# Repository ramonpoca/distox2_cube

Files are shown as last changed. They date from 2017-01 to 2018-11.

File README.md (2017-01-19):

# Readme #

OpenSCAD models for distox2 calibration device by Mykyta Kozlov. Version 0.0.5.

# Brief #

Calibration device consists of 2 things: calibration solid with direction holes, distox2 mounting handle.

Currently there are 2 OpenSCAD models of solid: cube and truncated cuboctahedron.

Cube corresponds to calibration directions used in [distox2 calibration manual](http://paperless.bheeb.ch/download/DistoX2_CalibrationManual.pdf).

Truncated cuboctahedron provides additional 12 calibration directions, saving 'original' cube ones.

Also provided 2 models of handle: 

1. To be printed from plastic and ready to use
2. More robust handle to use aluminiun pipe or shaft as main rotating unit. Aluminium part needs to be glued into plastic printed part. Optionally handle v.2 extension can be also used.

# HOWTO produce STL files for 3D printing #

1. Open .scad files in latest [OpenSCAD](http://www.openscad.org/).
2. Render (press F6).
3. Export to STL via menu item: File -> Export -> Export as STL.

# Pictures #

* Cube

Cube

* Truncated cuboctahedron

Truncated cuboctahedron

* Handle

Handle

* Handle v. 2

Handle v2

* Handle v. 2 extension

Handle v2 extension
Handle v2 extension bottom

# Sample mount #

Here goes an implementation example of mounting device to fix cube on tripod. Design by Vytis Vilkas.

* Bottom view

Bottom view

* Side view

Side view

* Alltogether

Alltogether

As it can be seen from photos above - cube is mounted to square O-shape rod by two non-magnetic screws.

There are space of 5 mm width left between rod surface and cube face - to allow free handle rotation, while doing calibration measurements along the rod.

Rod also has a bottom hole - for access while doing vertical calibration measurement with that hole.

For mounting truncated cuboctahedron rod needs to have additional 45 degree hole to acces calibration hole in cube edge.

Also solid aluminium handle is shown. If doing handle from plastic, especially handle v2 - you need to glue 8 mm nonmagnetic 
rotation axis into 8 mm handle hole. For truncated cuboctahedron axis length needs to be 2 time more than in original design,
again - to access hole in cube edge. Additionally handle v2 extension can be used to access keyhole trough the rod.

Second hole in handle's U-shape used for mounting leica disto x310 to handle by 1/4" nonmagnetic screw (same as used to mounting photo camera to tripod).

In the left side there are aluminium nut and aluminium screw, both having 1/4" screw are mounted through the rod to each other.
They are in 'transportation mode'. When doing calibration - screw is used to attach leica to rotating handle, nut is used to mount rod to standart tripods plate.

# Notes #

Handle design is compatible with leica disto X310 (E7400x US version of the X310) only.

To model your own calibration shape solid you can use Wolfram Mathematica notebook DistoX_Cube_shape_variants.nb,
which provides sample usage of polyhedron data and the way how to convert it into OpenSCAD format. You need Wolfram Mathematica to open such file.

After printing hole and shaft surfaces need to be finished to desired level of friction. Usualy enough to freely rotate, but not falling down being inserted into hole.

Handle v2 and Truncated cuboctahedron also has squared keys to optionally restrict rotation step around calibration axis by multiply of 45 degree.

# Sample usage video #

Calibrating distox2 with cube in Lithuanian forest (https://www.youtube.com/watch?v=A7fQdz4pPtE)

# Discussion #

* English

1. [Reddit's /r/caving](https://www.reddit.com/r/caving/comments/56mu1l/distox2_calibration_device/).
2. [Cavers of Facebook](https://www.facebook.com/groups/2205123638/permalink/10153870390228639/).

* Russian

1. [Speleoukraine forum](http://www.speleoukraine.org/forum/viewtopic.php?f=19&t=267&sid=d517e04313eabdb7c628c214259eedf8#p4050).
2. [Soumgan forum](http://www.soumgan.com/phpBB2/viewtopic.php?f=24&t=798).

# Contact #

If any questions contact nikita.kozlov@gmail.com

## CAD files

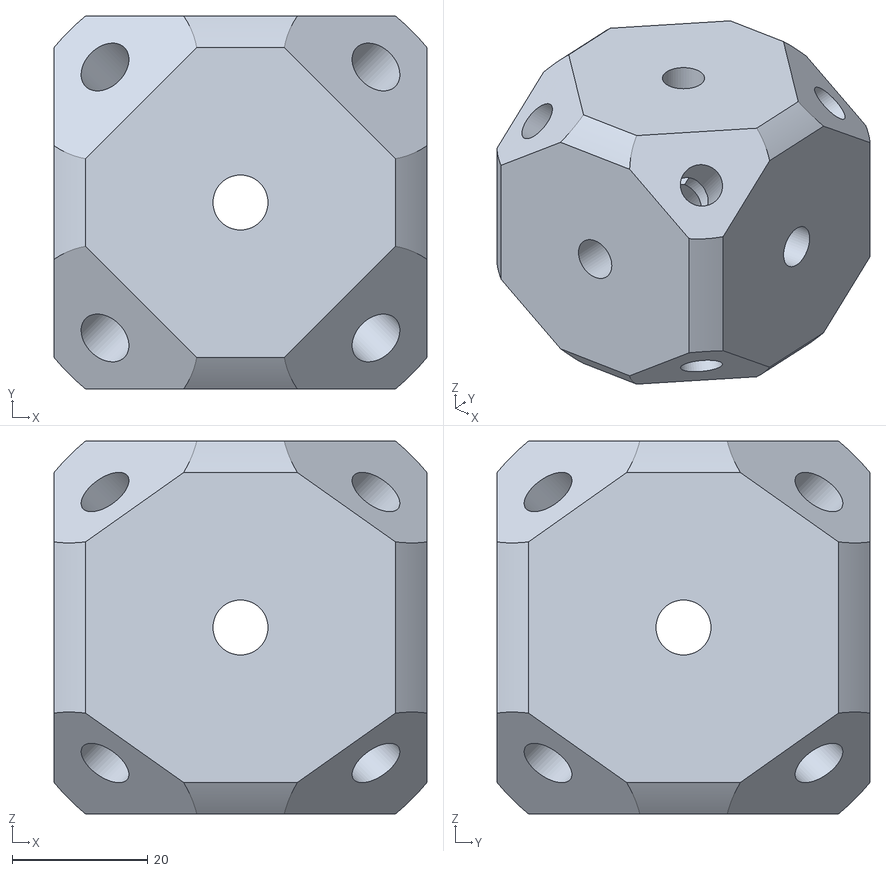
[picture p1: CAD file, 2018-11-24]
distox2_calibration_cube.stl
55.0 x 55.0 x 55.0

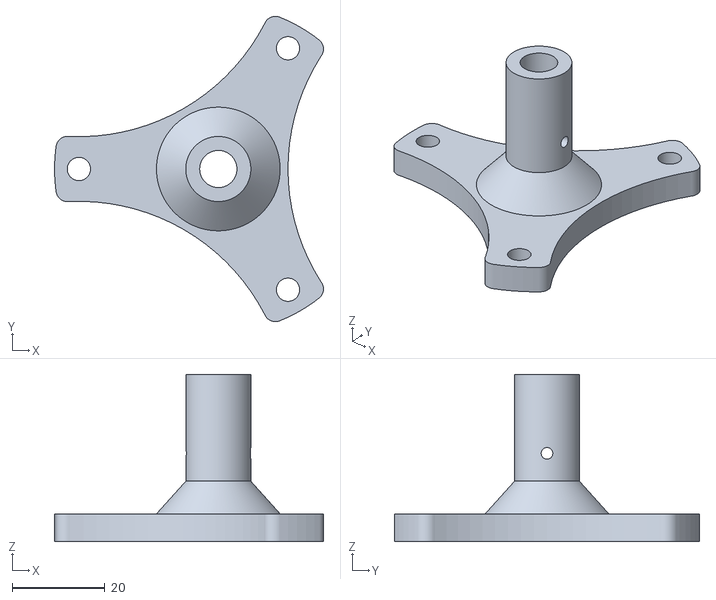
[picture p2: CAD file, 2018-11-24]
distox2_calibration_handle_v4_top.stl
57.9 x 65.7 x 36.0

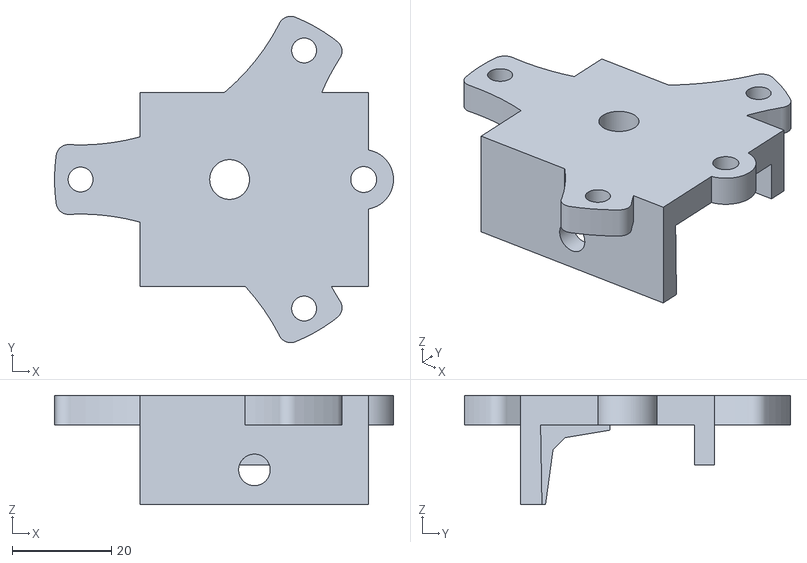
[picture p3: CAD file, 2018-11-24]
distox2_calibration_handle_v4_bot.stl
68.2 x 65.7 x 22.0

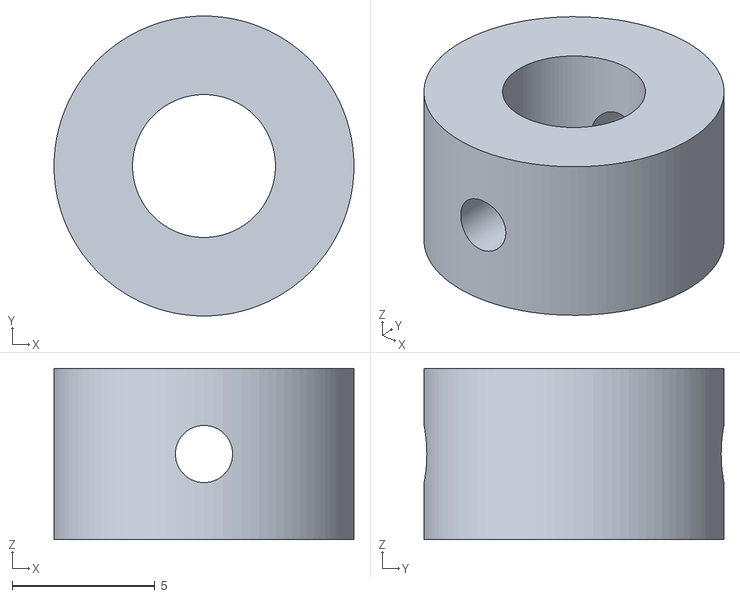
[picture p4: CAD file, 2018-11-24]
distox2_calibration_handle_v4_bolt_head.stl
10.5 x 10.5 x 6.00

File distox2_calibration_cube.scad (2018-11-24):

/// DistoX2 calibration cube by Mykyta Kozlov

hf = 48; // subdivision hole quadrics
rf = 1000; // subdivision for round edges
da = 54.735610317245346; // angle of main cube diagonal

module hole() {
  cylinder (90, 4.05, 4.05, true, $fn=hf);
};

module edgeround() {
  cylinder(55, 35.75, 35.75, true, $fn=rf);
}

module cornercut() {
  cube([68.2, 100, 100], true);
}

intersection() {
  difference() {
    // main cube
    cube(55,true); 
    // main holes
    hole();
    rotate ([90,0,0]) hole();
    rotate ([0,90,0]) hole();
    // diagonal holes
    rotate ([0, da, 45]) hole();
    rotate ([0, da, 135]) hole();
    rotate ([0, da, -45]) hole();
    rotate ([0, da, -135]) hole();  
  }
  // round cube edges
  edgeround();
  rotate ([90, 0, 0]) edgeround();
  rotate ([0, 90, 0]) edgeround();
  // cut cube vertices
  rotate ([0, 45, 45]) cornercut();
  rotate ([0, -45, 45]) cornercut();
  rotate ([0, 45, -45]) cornercut();
  rotate ([0, -45, -45]) cornercut();
}

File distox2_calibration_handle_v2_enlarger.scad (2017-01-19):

/// DistoX2 calibration handle v.2 enlagrer by Mykyta Kozlov

sn=100; // subdivision for cylinders

module key() {
  linear_extrude(height = 2.5, center = false, convexity = 10, twist = 0)
  square(8.05,true);
}

difference() {
  difference() {
    union() {
      cylinder(h=35, d1=14, d2=14, center=true, $fn=2*sn);
      translate([0,0,17.5]) key();
    }
    translate([0,0,-17.5]) key();
  }
  cylinder(h=42, d1=8, d2=8, center=true, $fn=2*sn);
}

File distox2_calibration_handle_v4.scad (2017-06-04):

/// DistoX2 calibration handle v.3. by Mykyta Kozlov

sn=100; // subdivision for cylinders

module U_shape_mount_holes(coffset, rotation, holediam, holecentering) {
  rotate([0,0,rotation]) {
    translate([coffset,0,0]) 
      cylinder(h=10, d1=holediam, d2=holediam, center=holecentering, $fn=sn);
    rotate([0,0,120]) translate([coffset,0,0]) 
      cylinder(h=10, d1=holediam, d2=holediam, center=holecentering, $fn=sn);
    rotate([0,0,-120]) translate([coffset,0,0])
      cylinder(h=10, d1=holediam, d2=holediam, center=holecentering, $fn=sn);
  }
}

module precession_centering_plate(extrudeh) {
linear_extrude(height = extrudeh, center = true, convexity = 10, twist = 0)
  minkowski($fn=sn) {
    circle(d=5, $fn=sn);
    difference() {
      circle(d = 65.5, center=true, $fn=sn);
      
      cutd = 95;  
    
      translate([60,0,0])
        circle(d = cutd, center=true, $fn=sn);
    
      rotate([0,0,120]) translate([60,0,0]) 
        circle(d = cutd, center=true, $fn=sn);
    
      rotate([0,0,-120]) translate([60,0,0]) 
        circle(d = cutd, center=true, $fn=sn);
    }
  }
}

module U_shape() {
  difference() {
    // handle U-shape
    union () {
      rotate([90,0,90])
        linear_extrude(height = 46, center = false, convexity = 10, twist = 0)
        polygon([[0,0],[0,20],[4+16*tan(1),20],[4,4],[35,4],[35,12],[39,12],[39,0]]);
    
    
      translate([28, 21.5, 1])
        rotate([0,0,180])
          precession_centering_plate(6);
            
      translate([0, 0, -2])
      cube([46, 39, 2],false);
        
      translate([1, 21.5, 1])
      cylinder(h=6, d1=12, d2=12, center=true, $fn=sn);
    }
    
    // hole for leica fix
    translate([23, 0, 13]) rotate([90, 0, 0]) 
      cylinder(h=9, d1=6.35, d2=6.35, center=true, $fn=sn); // For 1/4-20 UNC
    
    // main axis hole  
    translate([28, 21.5, -1.5])
      cylinder(h=12, d1=8, d2=8, center=true, $fn=sn);
    
    translate([28, 21.5, 0])
      U_shape_mount_holes(30, 0, 5, true);
    
    translate([1, 21.5, 1])
      cylinder(h=7, d1=5.2, d2=5.2, center=true, $fn=sn);
  }
}

module Rigidity_Rib() {
  linear_extrude(height=8.25, center=false, convexity=10, twist=0)
  polygon([[0,0],[0,1],[11,2.5],[13.5,5],[15,14],[16,14],[16,0]]);
}

module axis_RigidityRib() {
  translate([0,0,3])  
  difference() {
    union() {
      translate([0,0,3])
      rotate_extrude(angle = 360, convexity = 10, $fn = 2*sn)
      polygon([[4,0],[13.3,0],[7,7],[7,30],[4,30]]);
      
      precession_centering_plate(6);
    }
    U_shape_mount_holes(30, 180, 5, true);
    
    cylinder(h=8, d1=8, d2=8, center=true, $fn=sn);
    
    
    translate([0,0,16]) rotate([0,90,0])
    cylinder(h=30, d1=2.5, d2=2.5, center=true, $fn=sn);
  }
}

module handle_mount() {
  translate([28, -21.5, 0])
  rotate([0,180,0])
  union() {
    U_shape();
    translate([3.75, 4, 20]) rotate([0, 90, 0])
    Rigidity_Rib();
    translate([22+8.25+3.75, 4, 20]) rotate([0, 90, 0])
    Rigidity_Rib();
  }
}

translate([0,0,-2])
handle_mount();
color("RoyalBlue", 0.7)
axis_RigidityRib();

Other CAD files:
distox2_calibration_handle_v4_bolt_head.scad
distox2_calibration_handle.scad
distox2_calibration_handle_v2.scad
distox2_calibration_handle_v3.scad
distox2_calibration_truncatedcuboctahedron.scad
distox2_handle_screw_head.scad

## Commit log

2016-10-19 Fix for handle, since distox2 mounting plate are not parallel to laser
    [distox2_calibration_handle.scad]
2016-10-19 Use linear_extrude to design handle U-shape instead of union of parallelepipeds
    [distox2_calibration_handle.scad]
2016-11-12 Move handle to correct position, thanks to Eugeniy Zaharov
    [distox2_calibration_handle.scad]
2017-01-18 Initial Import of 'Truncated Cuboctahedron' variant of calibration device, for 'accuracy addicts', +12 new calibration directions, saving old cube ones
    [distox2_calibration_truncatedcuboctahedron.scad]
2017-01-18 use 48 as subdivision for holes, instead of 100
    [distox2_calibration_cube.scad]
2017-01-18 Update README with link to distox calibration manual
2017-01-18 add champher to make handle more robust
    [distox2_calibration_handle.scad]
2017-01-18 Initial import of handle version 2, to use with 8mm aluminium shaft
    [distox2_calibration_handle_v2.scad]
2017-01-19 use modules to simplify code
    [distox2_calibration_cube.scad]
2017-01-19 Add keys to truncatedcuboctahedron and handle v2 to optionally restrict rotation step by 45 degree
    [distox2_calibration_handle_v2.scad, distox2_calibration_truncatedcuboctahedron.scad]
2017-01-19 Update README with sample mount
2017-01-19 Initial import of handle v.2 enlarger to use with bottom 45 degree edge keyhole
    [distox2_calibration_handle_v2_enlarger.scad]
2017-01-26 more robust handle v2 with fixed support angle
    [distox2_calibration_handle_v2.scad]
2017-01-31 comment-out keys and add holes for fixing at the rod
    [distox2_calibration_truncatedcuboctahedron.scad]
2017-01-31 initial import of handle v.3, made from 2 separate parts, with U-shape having rigidity rids
    [distox2_calibration_handle_v3.scad]
2017-02-04 Add mounting legs to axisrid and corrresponding holes for m4 thread in U-shape for final accurate handle assembly
    [distox2_calibration_handle_v3.scad]
2017-02-05 Initial import of cube mount washer and handle screw head
    [distox2_handle_screw_head.scad, distox2_mount_washer.scad]
2017-03-10 Integrate mount washer inside truncatedcuboctahedron
    [distox2_calibration_truncatedcuboctahedron.scad, distox2_mount_washer.scad]
2017-03-10 Add support triangles for truncatedcuboctahedron
    [distox2_calibration_handle_v2.scad, distox2_calibration_truncatedcuboctahedron.scad]
2017-05-04 add hole to rigidity rib, cleanup code
    [distox2_calibration_handle_v3.scad]
2017-05-04 initial import of precession-adjusting handle
    [distox2_calibration_handle_v4.scad, distox2_calibration_handle_v4_bolt_head.scad]
2017-06-04 more robust handle v.4
    [distox2_calibration_handle_v4.scad]
2018-11-24 Personal modifications and stl models
    [distox2_calibration_cube.scad, distox2_calibration_cube.stl, distox2_calibration_handle_v4_bolt_head.stl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]
